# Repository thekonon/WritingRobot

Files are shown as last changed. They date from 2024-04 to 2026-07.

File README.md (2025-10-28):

# WritingRobot
Draw anything using robot!

## Overview

Robot is made of:
- Control part that runs on __Raspberry PI4__
- CAN communication using __MPC2515__ modules
- <del>__Arduino__ Nano clone</del>
- STM32 Bluepill (STM32F103C6T6
- Two __stepper motors drivers__

# Schemes

## Electrical wiring

Arduino:

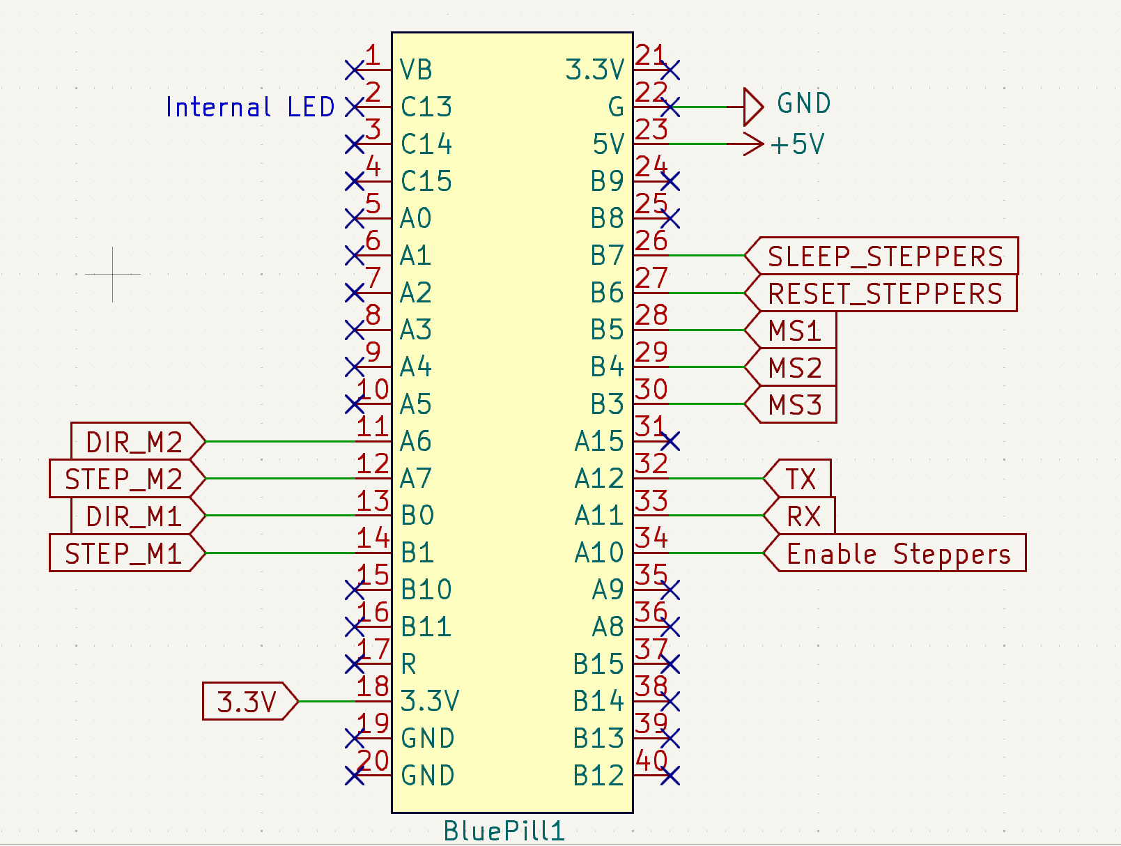
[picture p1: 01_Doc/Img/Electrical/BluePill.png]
Arduino


Stepper motors

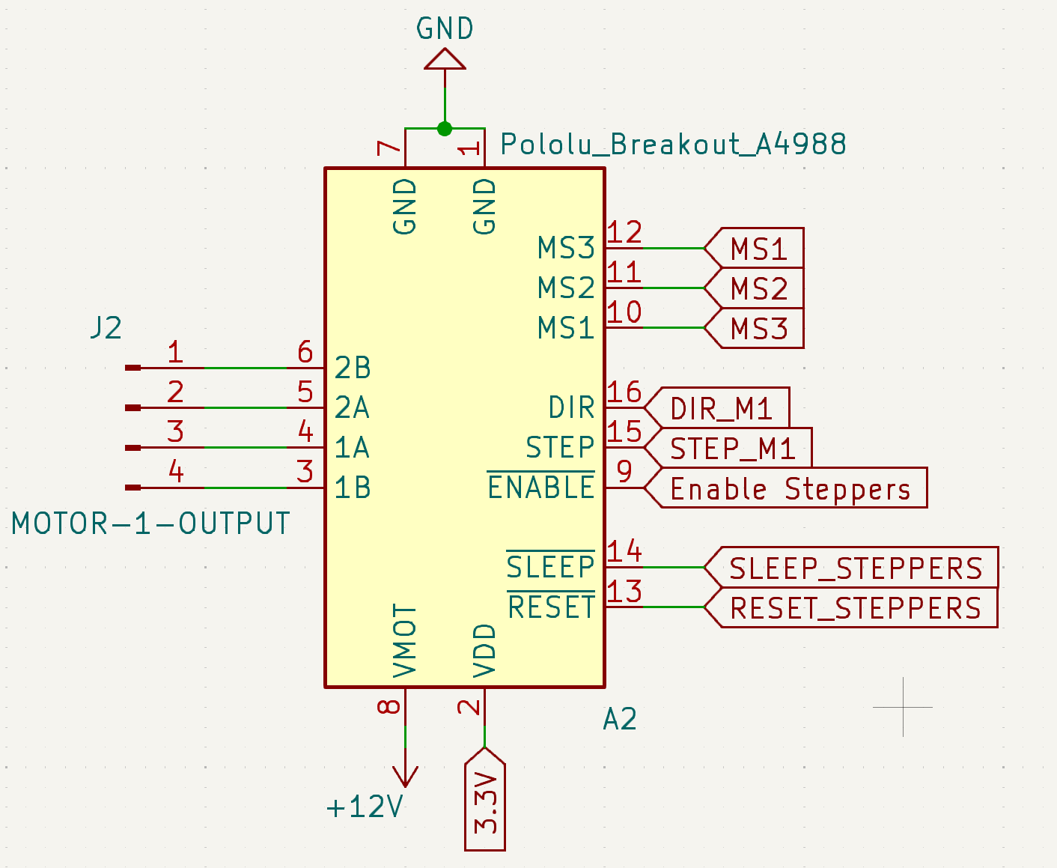
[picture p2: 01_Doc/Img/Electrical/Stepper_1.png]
Stepper1

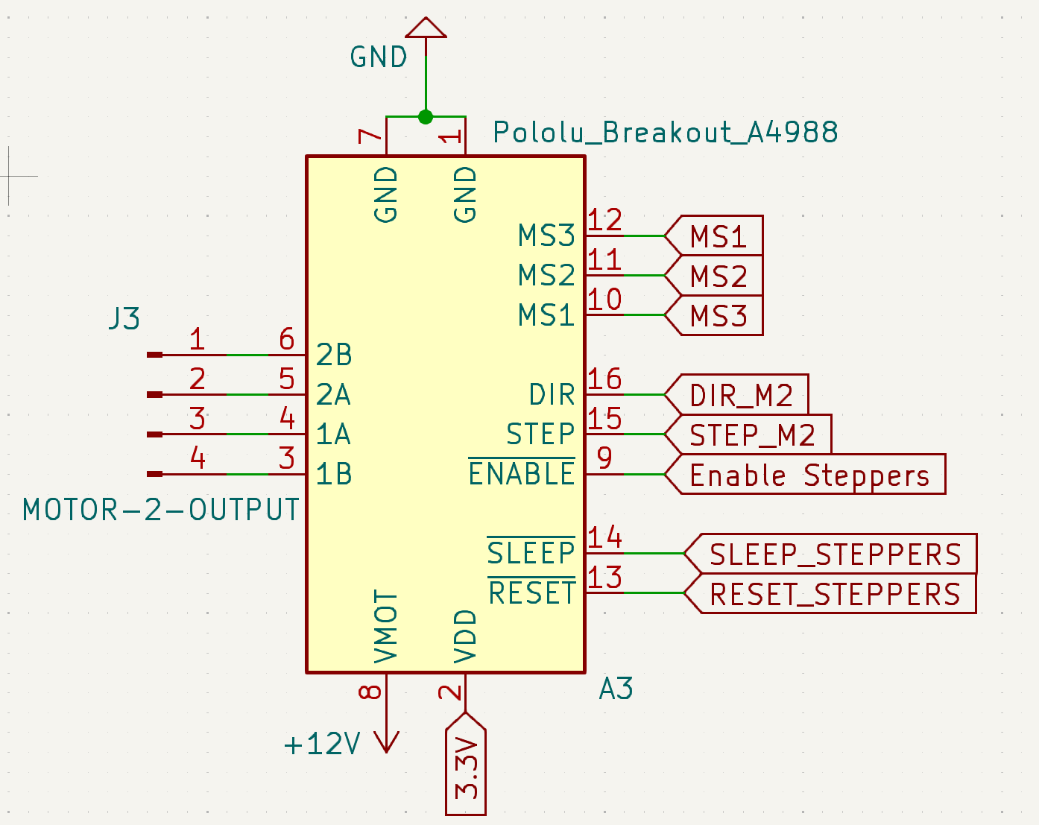
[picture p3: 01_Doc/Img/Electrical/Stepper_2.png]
Stepper2


Powerline

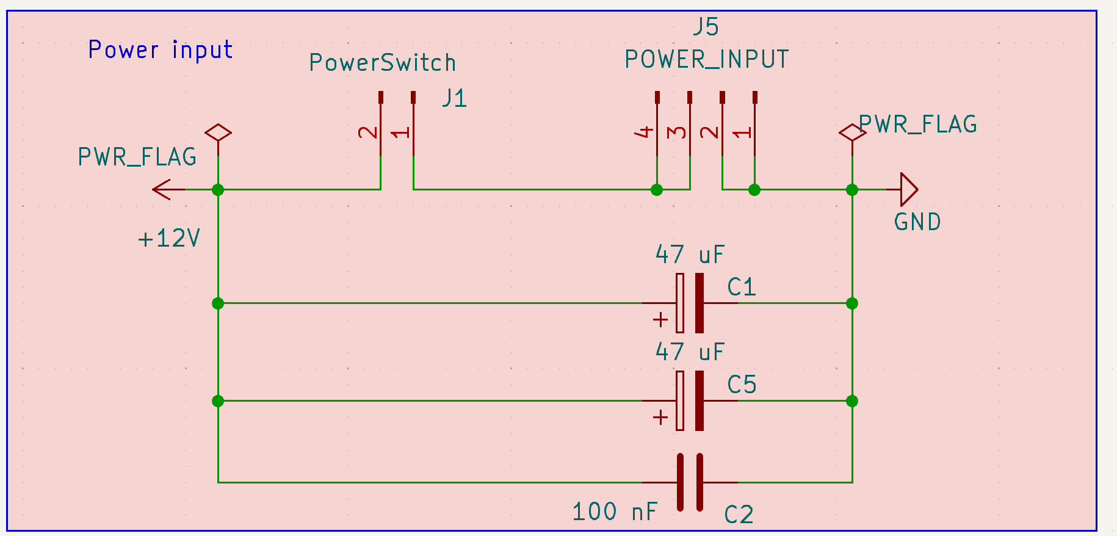
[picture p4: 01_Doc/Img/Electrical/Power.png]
POWERLINE


MCP2551 CANH/L -> Rx/Tx data module

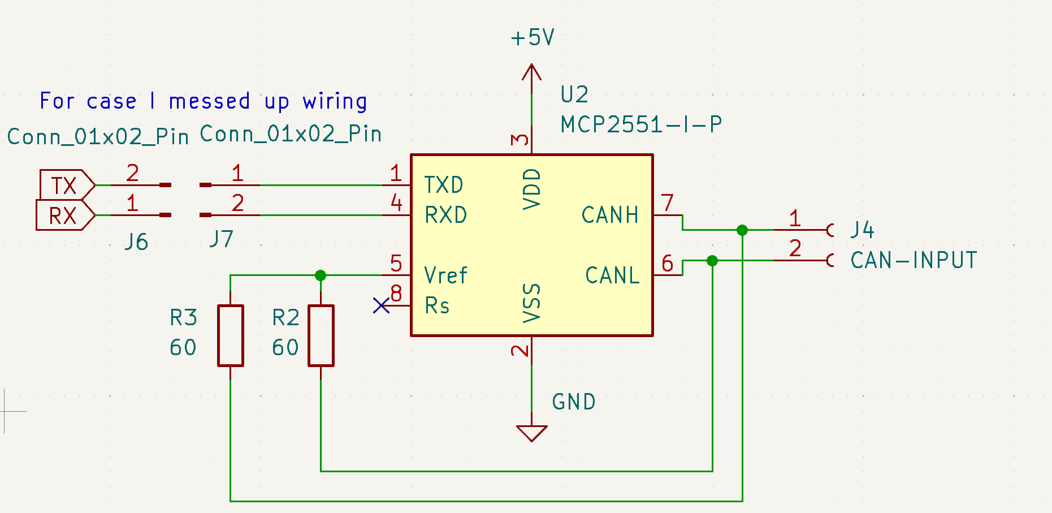
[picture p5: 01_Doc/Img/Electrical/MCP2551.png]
MCP2551


L7805 -> 12V -> 5V/1A 

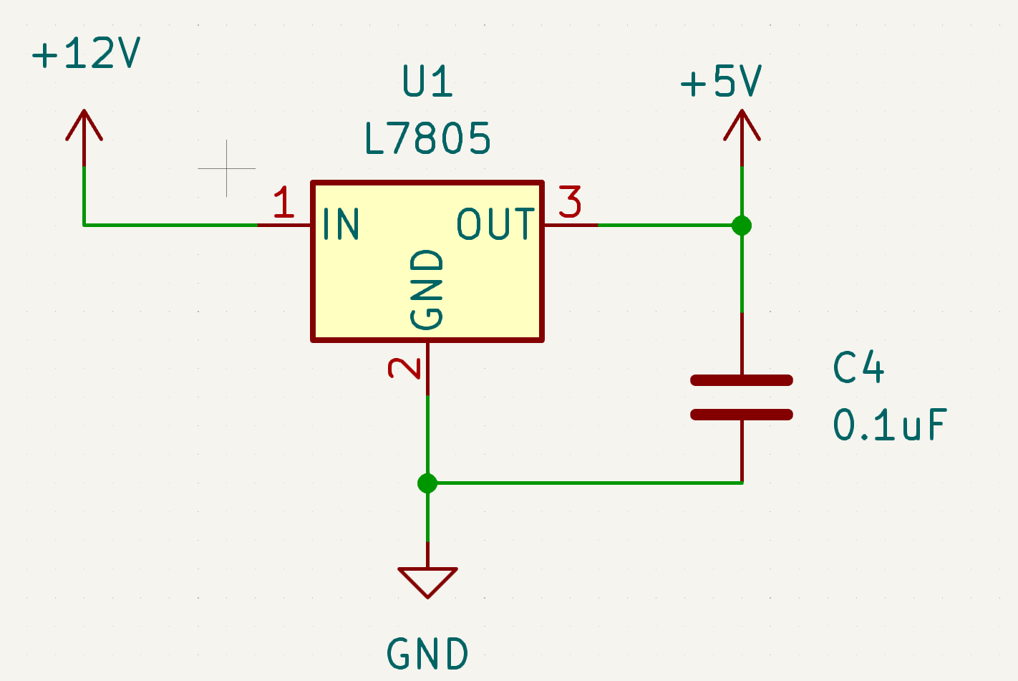
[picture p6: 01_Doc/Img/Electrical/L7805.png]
L7805


## Board design

Wiring scheme of actual PCB

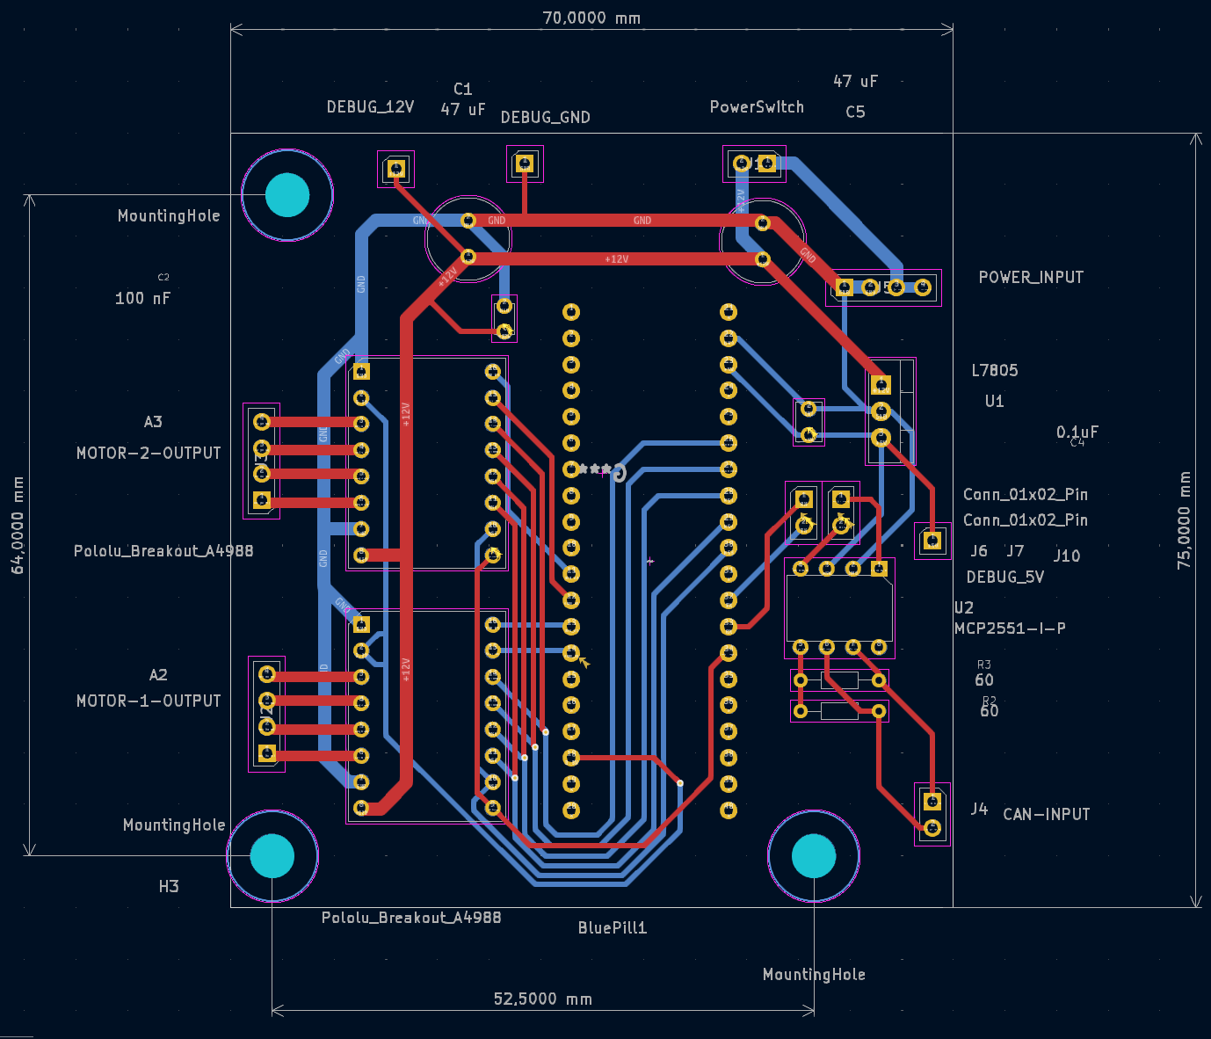
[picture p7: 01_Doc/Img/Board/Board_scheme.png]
BoardScheme


3D view to the board without and with modules

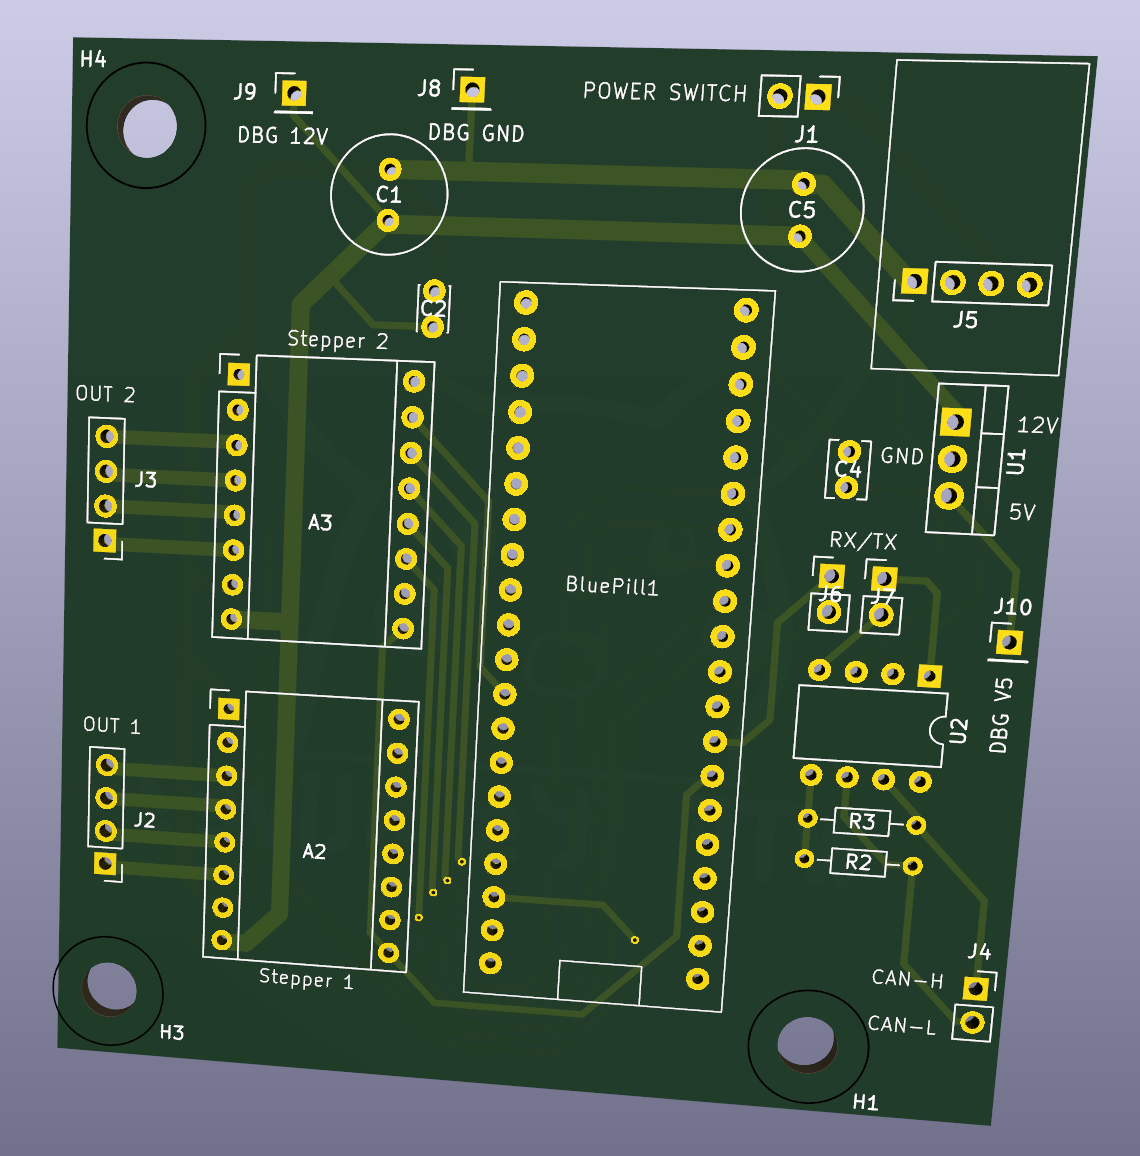
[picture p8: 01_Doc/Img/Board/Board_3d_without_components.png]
BoardWithoutComponents

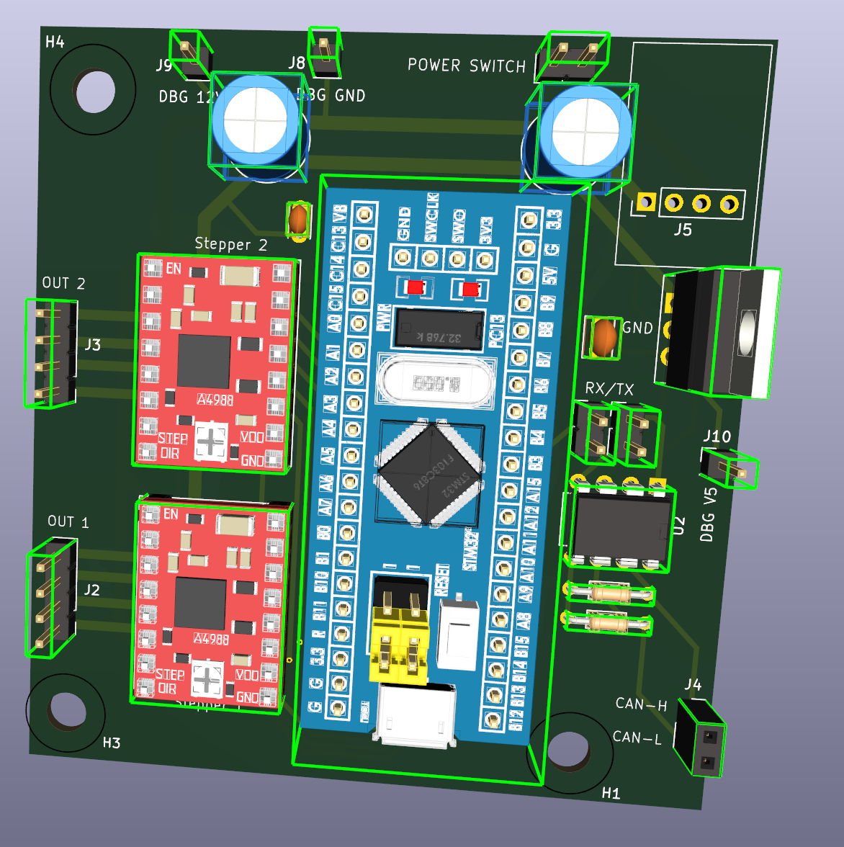
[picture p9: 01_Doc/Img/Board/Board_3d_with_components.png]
BoardWithComponents


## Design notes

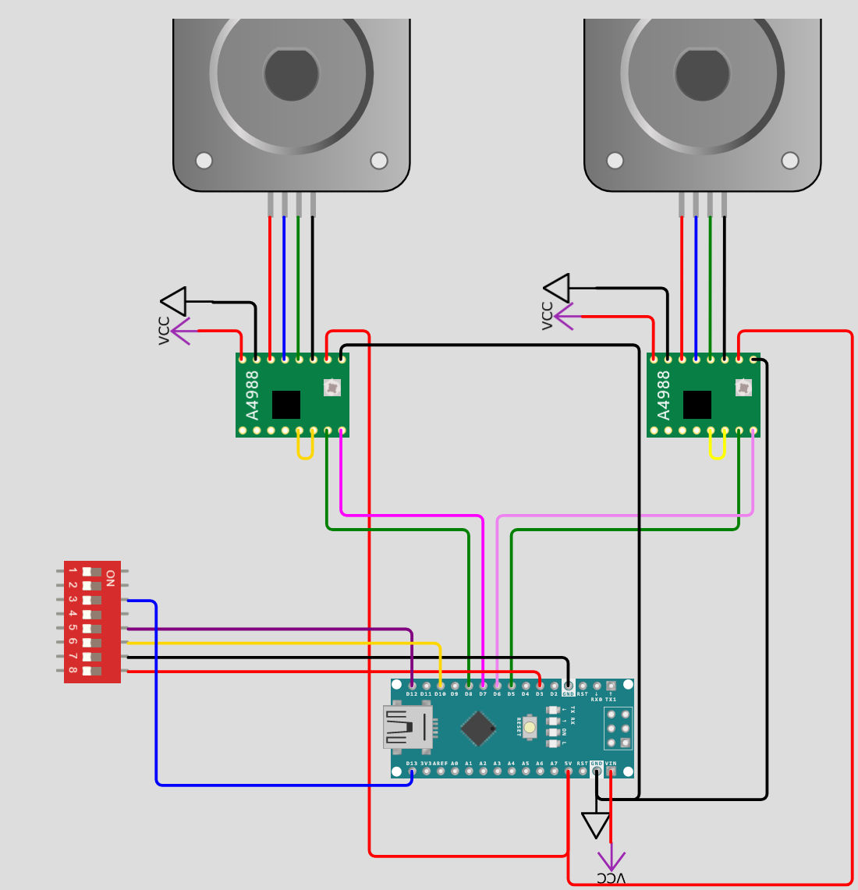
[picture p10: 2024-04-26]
Arduino.png

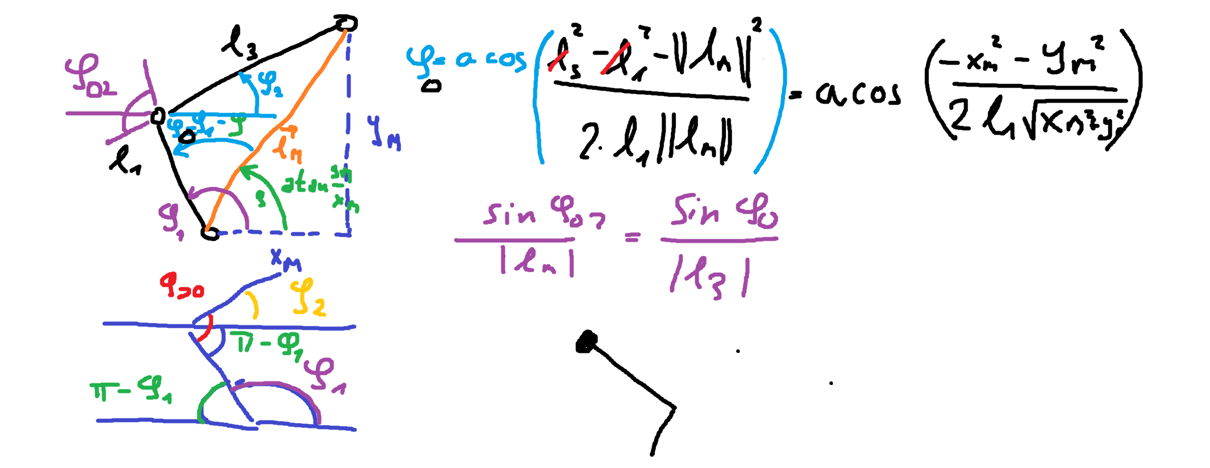
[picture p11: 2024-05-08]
01_Doc/Img/Computation/computation.png

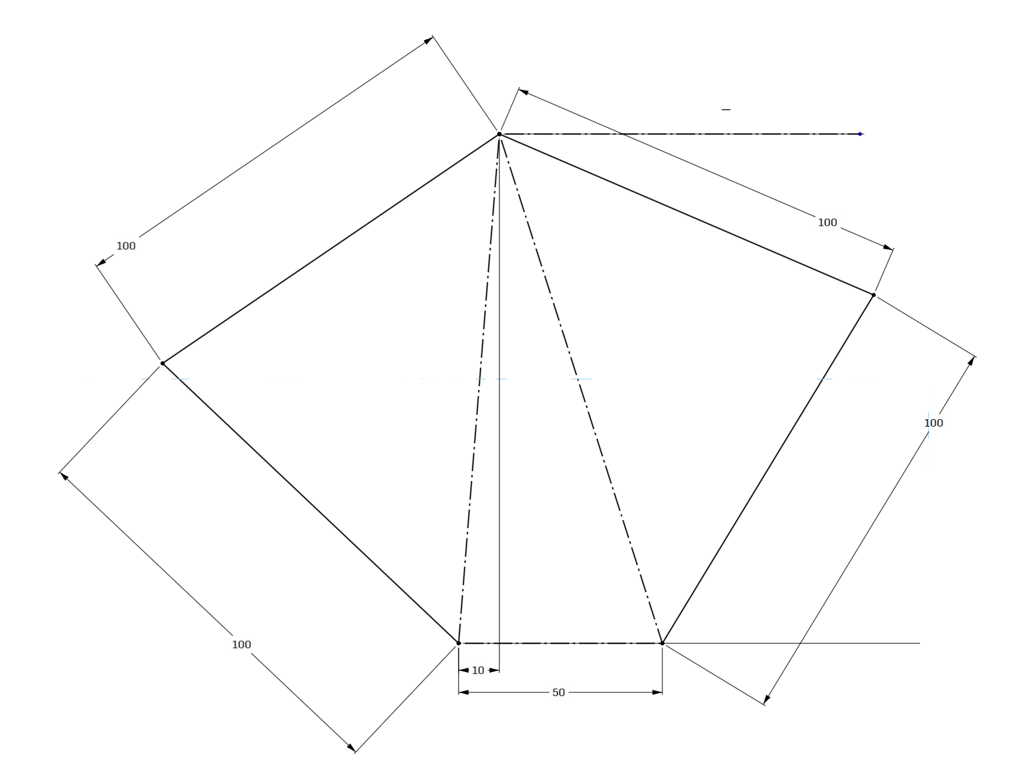
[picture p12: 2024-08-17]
01_Doc/Img/Computation/Comp_new.png

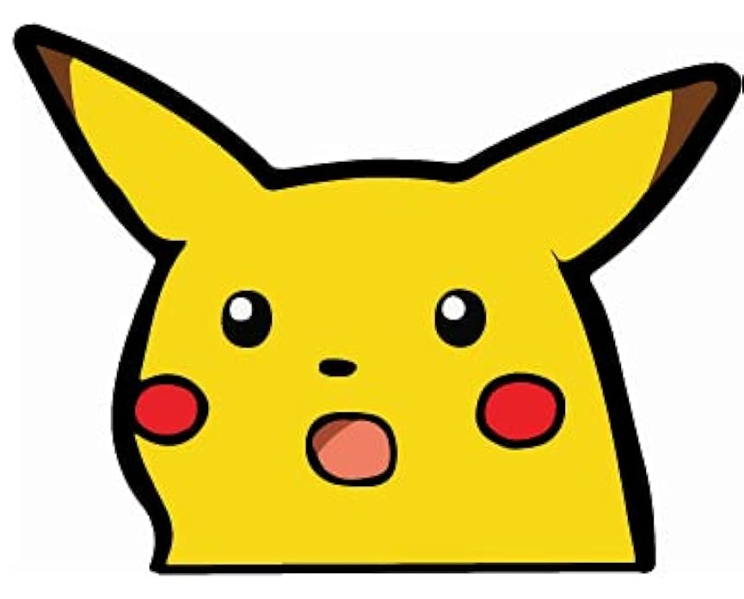
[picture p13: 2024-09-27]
02_HW/board/imgs/pikachu.png

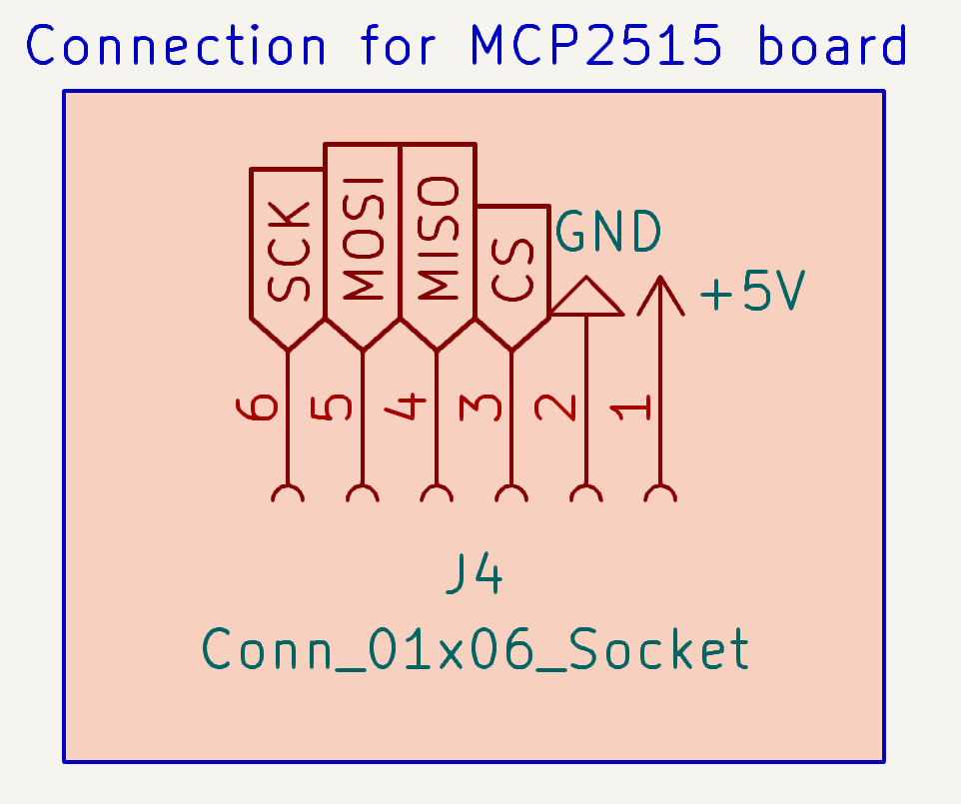
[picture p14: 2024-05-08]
01_Doc/Img/Electrical/MCP2515.png

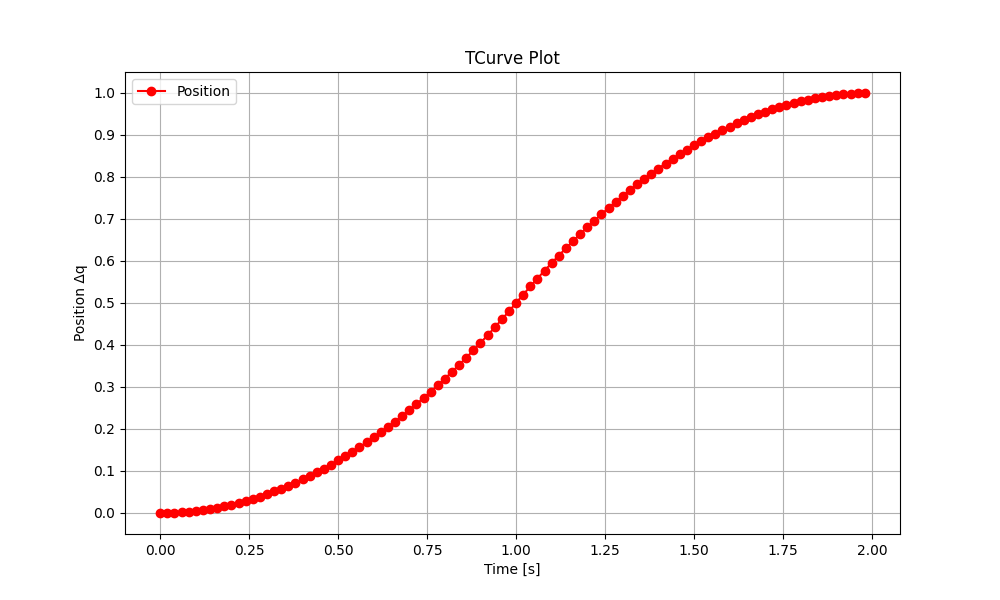
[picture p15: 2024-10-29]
01_Doc/Img/Computation/TCurve/Symetry.png

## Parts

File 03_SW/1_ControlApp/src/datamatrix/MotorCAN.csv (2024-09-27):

Message name | Signal Name | ID | Unit | Length [bits] | Start Bit | Value Range | Initial Value | From | Description
Config_steps | Microstepping_M1 | 100 | / | 3 | 0 | 8 | 8 | MCU | Value of microstepping set up on A4988 for Motor 1
Config_steps | Microstepping_M2 | 100 | / | 3 | 3 | 8 | 8 | MCU | Value of microstepping set up on A4988 for Motor 2
Config_cur_step | Motor_1_cur_step | 101 | / | 14 | 0 | 16384 | 0 | MCU | Current step for Motor 1
Config_cur_step | Motor_2_cur_step | 101 | / | 14 | 14 | 16384 | 0 | MCU | Current step for Motor 2
Config_lengths | Length_1 | 102 | mm | 12 | 0 | 4096 | 100 | MCU | Lenght 1 in mm
Config_lengths | Length_2 | 102 | mm | 12 | 12 | 4096 | 100 | MCU | Lenght 2 in mm
Config_lengths | Length_3 | 102 | mm | 12 | 24 | 4096 | 100 | MCU | Lenght 3 in mm
Config_lengths | Length_4 | 102 | mm | 12 | 36 | 4096 | 100 | MCU | Lenght 4 in mm
Config_lengths | Length_5 | 102 | mm | 12 | 48 | 4096 | 50 | MCU | Lenght 5 in mm
Config_firmware | Major | 103 | / | 8 | 0 | 255 | 0 | MCU | Major version of flashed firmware
Config_firmware | Minor | 103 | / | 8 | 8 | 255 | 0 | MCU | Minor version of flashed firmware
Req_mcu | Microsteps | 50 | / | 1 | 0 | 2 | 0 | * | Request MCU to broadcast Config_steps msg
Req_mcu | Cur_steps | 50 | / | 1 | 1 | 2 | 0 | * | Request MCU to broadcast Config_cur_step msg
Req_mcu | Lengths | 50 | / | 1 | 2 | 2 | 0 | * | Request MCU to broadcast Config_Lengths msg
Req_mcu | Firmware | 50 | / | 1 | 3 | 2 | 0 | * | Request MCU to broadcast Config_firmware msg
Set_motors | Motor_1 | 10 | / | 32 | 0 | 4294967296 | 0 | Controller | Set step for motor 1
Set_motors | Motor_2 | 10 | / | 32 | 32 | 4294967296 | 0 | Controller | Set step for motor 2
Set_stepps | Motor_1 | 15 | / | 65 | 0 | 16384 | 0 | Controller | Set step for motor 1 without moving motors

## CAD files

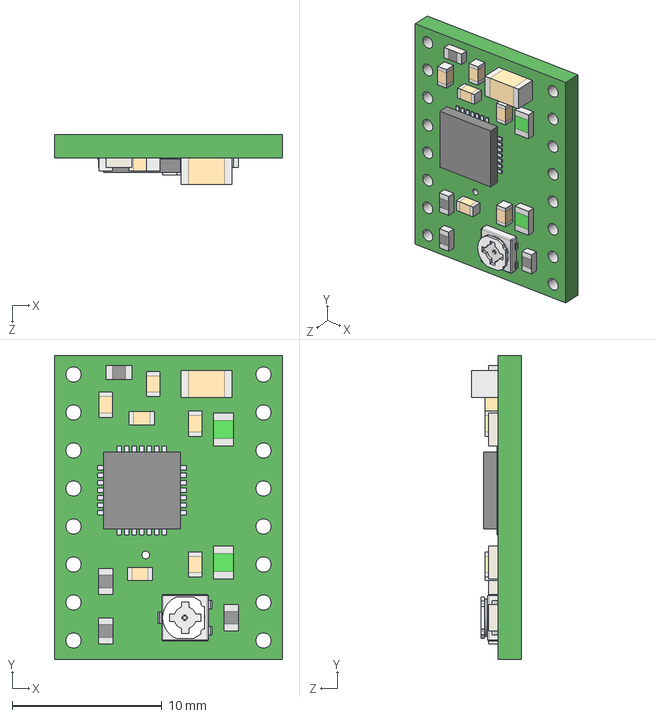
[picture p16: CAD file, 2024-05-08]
02_HW/board/extra_models/a4988-stepper-motor-driver-carrier.step
15.2 x 20.3 x 3.37 mm

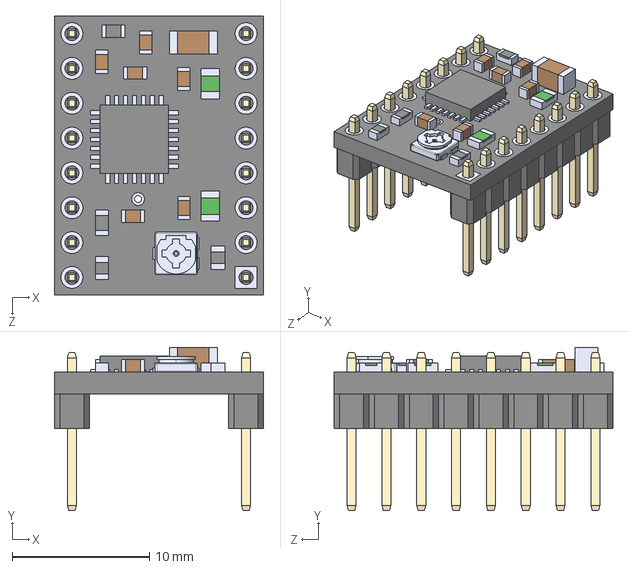
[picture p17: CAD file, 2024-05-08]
02_HW/board/extra_models/A4988 STEPPER MOTOR DRIVER CARRIER--3DModel-STEP-56544.STEP
15.2 x 11.9 x 20.3 mm

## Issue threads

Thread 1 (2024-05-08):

Add electric schamatics to README

thekonon, 2024-05-08:
Get screen shots from KiCAD and put it to main README or create a Wiki page for that reason.

thekonon, 2024-05-08:
Solved
Schematics added

Closed 2024-05-08.

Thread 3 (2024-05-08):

Board design improvement

thekonon, 2024-05-08:
Current board design has many flaws.
- It lacks of all capacitors
- Wire thickness is the same for power and signal lines

Improving electric schematics and board design is necessary

thekonon, 2024-06-14:
Board was updated to more robust version in DEV 0fea8d8758f1854dfbefbe87e100ff577dfcd0db

thekonon, 2024-06-14:
It would be good to add the probe points - for osciloscope

thekonon, 2024-07-13:
New screenshots from new board are needed in readme.

thekonon, 2024-08-17:
Current board implementation -> the one utilized STM bluepill contains filtering capacitor in the input side, as well as 5V regulator

thekonon, 2024-09-25:
New board added, but I missed probe points, needs to be added before sending to manifacture

Closed 2024-10-23.

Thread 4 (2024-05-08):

Add tests for python modules

thekonon, 2024-05-08:
More python tests needs to be added so the code for robot control will be robust.

thekonon, 2024-06-14:
Check if exists eventually add them:

- Test of new CAN frame
- Add the test for arduino

thekonon, 2024-08-17:
Tests for arduino are not needed anymore, creation of communication libraries for STM is now topic

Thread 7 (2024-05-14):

Redesign CAN Message frame

thekonon, 2024-05-14:
Currently the idea is to split 8 bytes long CAN message to 4 + 4 bytes for each motor. The 4 bytes has following meaning:

- First byte is sign byte 0 = +, 1 = -
- Second and third bytes are the whole number angles in range 0-360 basicly
- last byte stands for decimal number

This is described inside value_to_hex function inside _helpers.py in control folder
```
        # 1st byte      - sign 0 - +
        # 2nd/3rd byte  - value before decimal
        # 4th byte      - after decimal value
        # e.g. 347.36 -> [0, 1, 91, 36]
```
The idea is that the sign is not needed at all and for bytes could be used as:
2 bytes for whole numbers
2 bytes for 3 decimal

e.g. 276.654° would be ->
01 14 (.) 02 8E

If this will be implemented, tests will need modifications, but most importantly the arduino code for reading CAN msgs will need to modify acordingly

thekonon, 2024-08-17:
This has been discussed, still shity design not utilizing full potencial of CAN msg. New plan is:

1. Have one msgs id to send 2 * 32 bit numbers representing a wanted state of motor
- that means if I have 19200 steps per revolution and current state is 0, sending 1678 means i want to move motor to 1678 state
- also msgs that sets or asks for current configuration is cool feature

So now python communication module should not send angle values but rather steps state of each motor. This has to be implemented.

thekonon, 2024-09-25:
New format is defined in MotorCAN communication definition in src/datamatrix

Message name,Signal Name,ID,Unit,Length [bits],Start Bit,Value Range,Initial Value,From,Description
Set_motors,Motor_1,10,/,32,0,4294967296,0,Controller,Set step for motor 1
Set_motors,Motor_2,10,/,32,32,4294967296,0,Controller,Set step for motor 2

Closed 2024-09-25.

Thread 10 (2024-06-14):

Create a script that does  the linear movement of motors

thekonon, 2024-06-14:
E.g. arduino gets info that it should move 30 steps with motor A and 45 with motor B, create a function that will send the steps to motors the way it is aproximately a strait line.

Advanced - add the circles / arcs

thekonon, 2024-10-23:
STM chip should get info about x and y position and interpolate linear movement there, this issue is pointless now

Closed 2024-10-23.

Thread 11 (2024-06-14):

Add a arduino script to project

thekonon, 2024-06-14:
Currently the arduino code is only in my PC, It is necessary to add it to the Git

thekonon, 2024-08-17:
Great to have it but, I'll move to STM32 (blupill probably) so this code is no longer needed. On the other hand new ticket for including STMCube code will be necessary

Closed 2024-08-17.

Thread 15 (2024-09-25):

Find out a best control strategy for controlling speed of the motors

thekonon, 2024-09-25:
MSGs over the CAN will send needed step position of the motors, STM should handle smooth acceleration and decceleration for smother movement of whole robot. Question is how to do that.

Ideas:
- add a msgs indicating to slow down

thekonon, 2024-10-23:
Currently it seems I will split my traectory to linear parts and each linear part will be controlled via timer interruption - i have to write about it to wiki

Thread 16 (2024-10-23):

Lessons learned - board design

thekonon, 2024-10-23:
Mistakes:

- The DC connection is not fitting -> it should have been closer to edge or use directly DC jack mount
- Make edges rounded
- Add holes dimesions to PCB silk layer on back

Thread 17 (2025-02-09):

Remove MS3 from BP3 and use it as a SWO pin.

thekonon, 2025-02-09:
Recently I found out for SWV you have to have SWO pin connected to STM LINK, unfortunately I have connected MS3 signal to that pin. Redesigning a board with this feature is a must.

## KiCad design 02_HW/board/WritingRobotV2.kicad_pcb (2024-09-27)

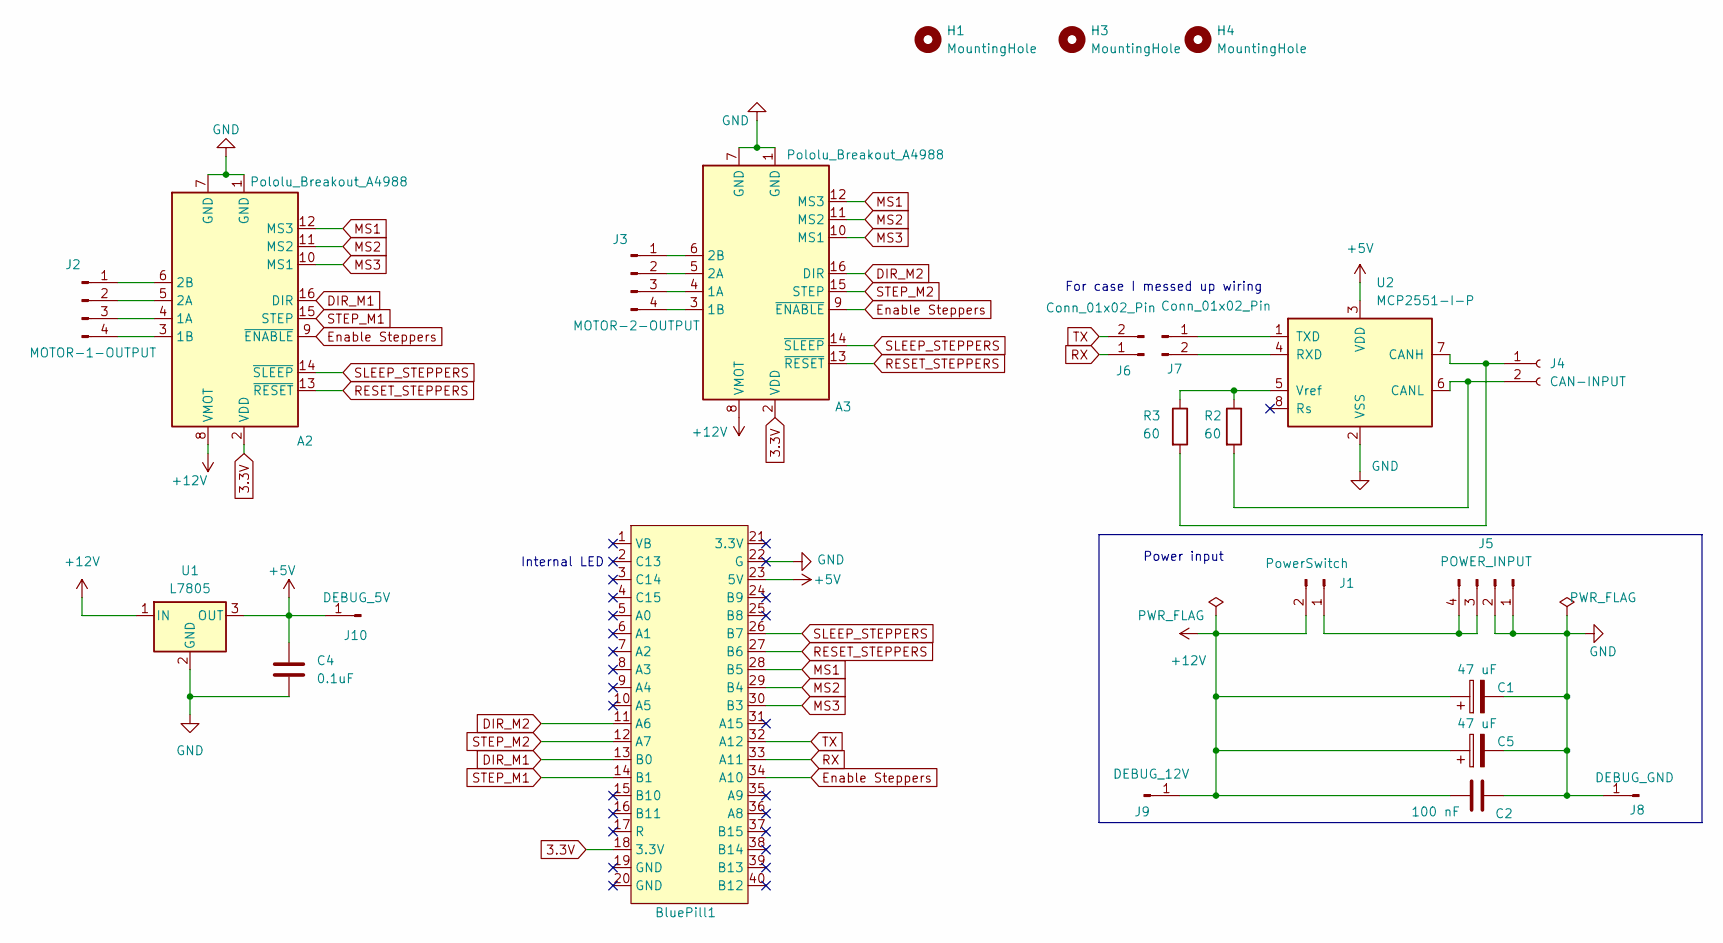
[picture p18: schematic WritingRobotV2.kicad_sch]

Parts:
A2, A3: Pololu_Breakout_A4988; Pololu_Breakout-16_15.2x20.3mm
BluePill1: BluePill
C1, C5: 47 uF; C_Radial_D8.0mm_H11.5mm_P3.50mm
C2: 100 nF; C_Disc_D3.0mm_W2.0mm_P2.50mm
C4: 0.1uF; C_Disc_D3.8mm_W2.6mm_P2.50mm
H1, H3, H4: MountingHole; MountingHole_4.3mm_M4
J1: PowerSwitch; PinHeader_1x02_P2.54mm_Vertical
J2: MOTOR-1-OUTPUT; PinHeader_1x04_P2.54mm_Vertical
J3: MOTOR-2-OUTPUT; PinHeader_1x04_P2.54mm_Vertical
J4: CAN-INPUT; PinSocket_1x02_P2.54mm_Vertical
J5: POWER_INPUT; PinHeader_1x04_P2.54mm_Vertical
J6, J7: Conn_01x02_Pin; PinHeader_1x02_P2.54mm_Vertical
J8: DEBUG_GND; PinHeader_1x01_P2.54mm_Vertical
J9: DEBUG_12V; PinHeader_1x01_P2.54mm_Vertical
J10: DEBUG_5V; PinHeader_1x01_P2.54mm_Vertical
R2, R3: 60; R_Axial_DIN0204_L3.6mm_D1.6mm_P7.62mm_Horizontal
U1: L7805; TO-220-3_Vertical
U2: MCP2551-I-P; DIP-8_W7.62mm

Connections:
3.3V: A2.2 (VDD), A3.2 (VDD), BluePill1.18 (3.3V)
+5V: BluePill1.23 (5V), C4.1, J10.1, U1.3 (OUT), U2.3 (VDD)
+12V: A2.8 (VMOT), A3.8 (VMOT), C1.1, C2.1, C5.1, J1.2, J9.1, U1.1 (IN)
DIR_M1: A2.16 (DIR), BluePill1.13 (B0)
DIR_M2: A3.16 (DIR), BluePill1.11 (A6)
Enable Steppers: A2.9 (~ENABLE), A3.9 (~ENABLE), BluePill1.34 (A10)
GND: A2.1 (GND), A2.7 (GND), A3.1 (GND), A3.7 (GND), BluePill1.22 (G), C1.2, C2.2, C4.2, C5.2, J5.1, J5.2, J8.1, U1.2 (GND), U2.2 (VSS)
MS1: A2.12 (MS3), A3.12 (MS3), BluePill1.28 (B5)
MS2: A2.11 (MS2), A3.11 (MS2), BluePill1.29 (B4)
MS3: A2.10 (MS1), A3.10 (MS1), BluePill1.30 (B3)
unnamed: A2.4 (1A), J2.3
unnamed: A2.3 (1B), J2.4
unnamed: A2.5 (2A), J2.2
unnamed: A2.6 (2B), J2.1
unnamed: A3.4 (1A), J3.3
unnamed: A3.3 (1B), J3.4
unnamed: A3.5 (2A), J3.2
unnamed: A3.6 (2B), J3.1
unnamed: J1.1, J5.3, J5.4
unnamed: J4.1, R3.2, U2.7 (CANH)
unnamed: J4.2, R2.2, U2.6 (CANL)
unnamed: J7.1, U2.1 (TXD)
unnamed: J7.2, U2.4 (RXD)
unnamed: R2.1, R3.1, U2.5 (Vref)
RESET_STEPPERS: A2.13 (~RESET), A3.13 (~RESET), BluePill1.27 (B6)
RX: BluePill1.33 (A11), J6.1
SLEEP_STEPPERS: A2.14 (~SLEEP), A3.14 (~SLEEP), BluePill1.26 (B7)
STEP_M1: A2.15 (STEP), BluePill1.14 (B1)
STEP_M2: A3.15 (STEP), BluePill1.12 (A7)
TX: BluePill1.32 (A12), J6.2

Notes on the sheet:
Internal LED
Power input
For case I messed up wiring

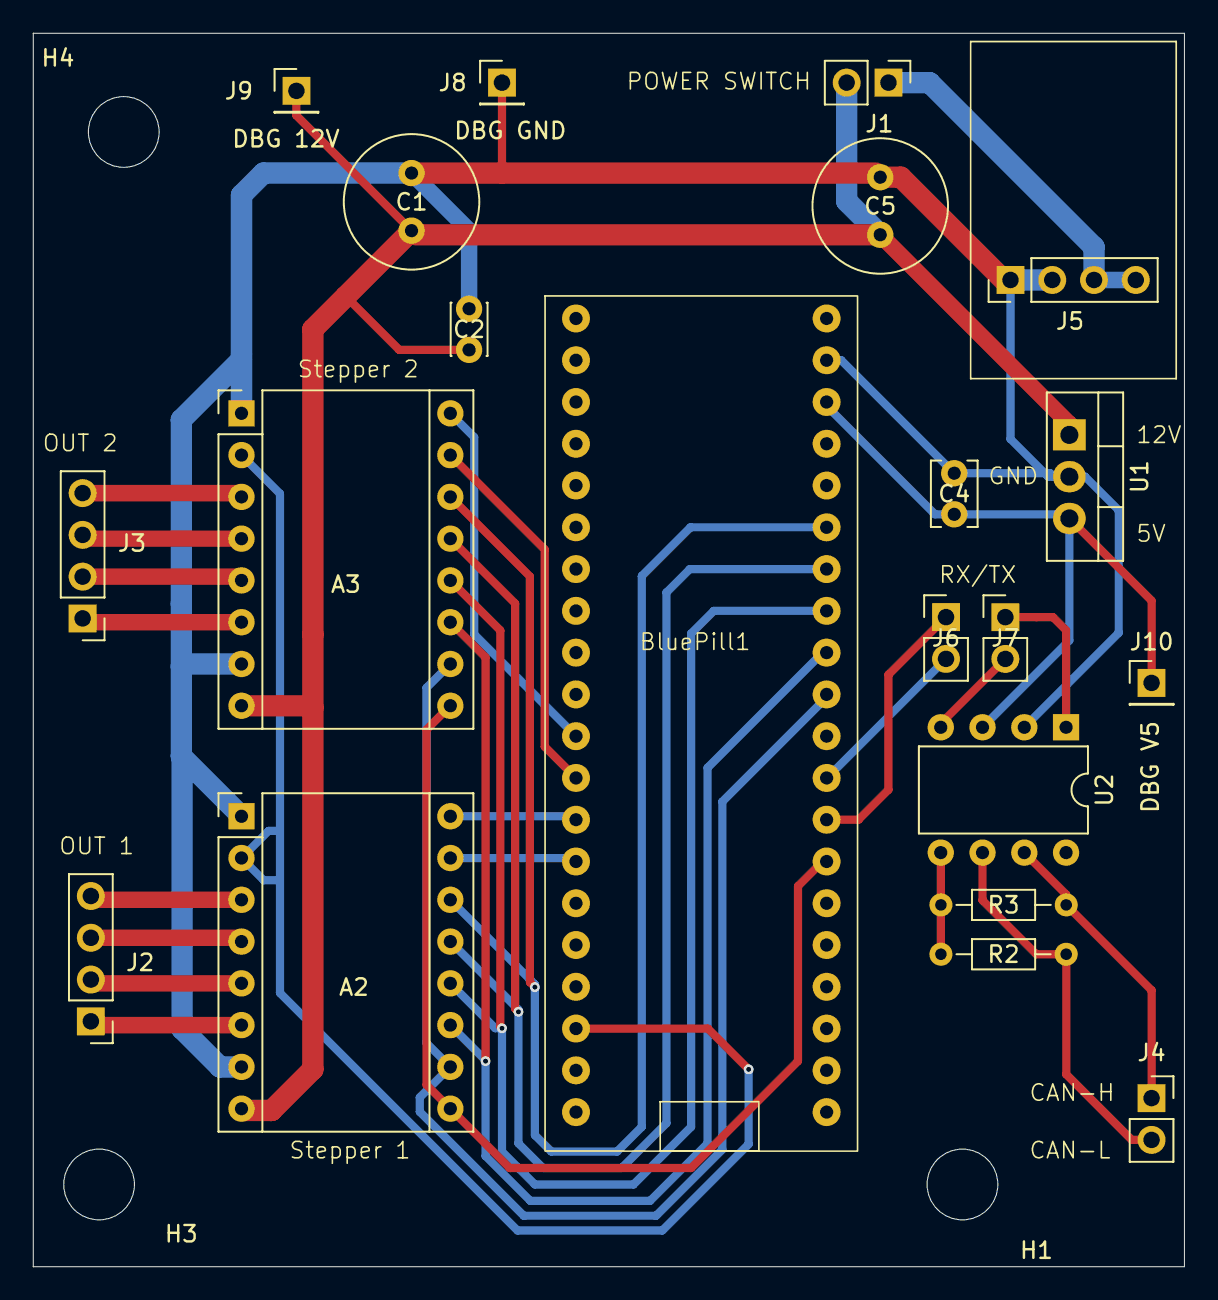
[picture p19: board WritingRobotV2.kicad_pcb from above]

Board: 2 copper layers, 70.0 x 75.0 mm, 24 parts (0 on the bottom side), 30 nets.

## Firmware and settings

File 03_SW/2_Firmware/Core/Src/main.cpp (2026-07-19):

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
/* Includes ------------------------------------------------------------------*/
#include "main.h"

CAN_HandleTypeDef hcan;

TIM_HandleTypeDef htim1;
TIM_HandleTypeDef htim2;
TIM_HandleTypeDef htim3;

void SystemClock_Config(void);
static void MX_GPIO_Init(void);
static void MX_CAN_Init(void);
static void MX_TIM2_Init(void);
static void MX_TIM1_Init(void);
static void MX_TIM3_Init(void);
static void MX_NVIC_Init(void);
/* USER CODE BEGIN 0 */

void HAL_TIM_PeriodElapsedCallback(TIM_HandleTypeDef *htim)
{
	if (htim->Instance == TIM2)
	{
		// Your interrupt code here (runs every 100 µs)
		HAL_GPIO_TogglePin(STEP_1_GPIO_Port, STEP_1_Pin);
		HAL_GPIO_TogglePin(STEP_2_GPIO_Port, STEP_2_Pin);
	}
}

void update_timer_period_us(uint32_t microseconds)
{
	uint32_t ticks = microseconds - 1; // at 1 MHz base
	__HAL_TIM_DISABLE(&htim2);         // optional: stop timer briefly
	__HAL_TIM_SET_AUTORELOAD(&htim2, ticks);
	__HAL_TIM_SET_COUNTER(&htim2, 0);  // reset counter if you want a clean start
	__HAL_TIM_ENABLE(&htim2);          // restart
}

/* USER CODE END 0 */

/**
 * @brief  The application entry point.
 * @retval int
 */
int main(void)
{

	/* MCU Configuration--------------------------------------------------------*/

	/* Reset of all peripherals, Initializes the Flash interface and the Systick. */
	HAL_Init();

	/* Configure the system clock */
	SystemClock_Config();

	/* Initialize all configured peripherals */
	MX_GPIO_Init();
	MX_CAN_Init();
	MX_TIM2_Init();
	MX_TIM1_Init();
	MX_TIM3_Init();

	/* Initialize interrupts */
	MX_NVIC_Init();
	/* USER CODE BEGIN 2 */
	// Enable interrupts
	HAL_TIM_Base_Start_IT(&htim2);

	// Enable stepper motors
	HAL_GPIO_WritePin(ENABLE_STEPPERS_GPIO_Port, ENABLE_STEPPERS_Pin, GPIO_PIN_RESET);
	HAL_GPIO_WritePin(SLEEP_STEPPERS_GPIO_Port, SLEEP_STEPPERS_Pin, GPIO_PIN_SET);
	HAL_GPIO_WritePin(RESET_STEPPERS_GPIO_Port, RESET_STEPPERS_Pin, GPIO_PIN_SET);

	HAL_GPIO_WritePin(DIR_1_GPIO_Port, DIR_1_Pin, GPIO_PIN_RESET);
	HAL_GPIO_WritePin(DIR_2_GPIO_Port, DIR_2_Pin, GPIO_PIN_RESET);
	HAL_GPIO_WritePin(STEP_1_GPIO_Port, STEP_1_Pin, GPIO_PIN_RESET);
	HAL_GPIO_WritePin(STEP_2_GPIO_Port, STEP_2_Pin, GPIO_PIN_RESET);

	TCurve curve;

	curve.setAcceleration(50.0f);
	curve.setDeltaPhi(10.0f);
	curve.setMaxVelocity(25.0f);

	if(curve.recalculateInternalVariables() != TCurveError::OK) Error_Handler();

	float t_max = curve.getTMax();

	/* USER CODE END 2 */

	/* Infinite loop */
	/* USER CODE BEGIN WHILE */
	uint32_t new_period = 200 - 1;   // 200 µs
	while (1)
	{
		/* USER CODE END WHILE */

		/* USER CODE BEGIN 3 */
		HAL_GPIO_TogglePin(LED_GPIO_Port, LED_Pin);
		HAL_Delay(500);
	}
	/* USER CODE END 3 */
}

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


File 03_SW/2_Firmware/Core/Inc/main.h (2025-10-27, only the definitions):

#define LED_Pin GPIO_PIN_13
#define LED_GPIO_Port GPIOC
#define DIR_2_Pin GPIO_PIN_6
#define DIR_2_GPIO_Port GPIOA
#define STEP_2_Pin GPIO_PIN_7
#define STEP_2_GPIO_Port GPIOA
#define DIR_1_Pin GPIO_PIN_0
#define DIR_1_GPIO_Port GPIOB
#define STEP_1_Pin GPIO_PIN_1
#define STEP_1_GPIO_Port GPIOB
#define ENABLE_STEPPERS_Pin GPIO_PIN_10
#define ENABLE_STEPPERS_GPIO_Port GPIOA
#define MS3_Pin GPIO_PIN_3
#define MS3_GPIO_Port GPIOB
#define MS2_Pin GPIO_PIN_4
#define MS2_GPIO_Port GPIOB
#define MS1_Pin GPIO_PIN_5
#define MS1_GPIO_Port GPIOB
#define RESET_STEPPERS_Pin GPIO_PIN_6
#define RESET_STEPPERS_GPIO_Port GPIOB
#define SLEEP_STEPPERS_Pin GPIO_PIN_7
#define SLEEP_STEPPERS_GPIO_Port GPIOB

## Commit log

2024-04-25 Init commit for files of first board iteration
    [WritingRobotV2-B_Cu.gbl, WritingRobotV2-B_Mask.gbs, WritingRobotV2-B_Paste.gbp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]
2024-05-08 Changed electrical layout Added 3d components to PCB Created photos for DOCU Modified Readme file
2024-05-08 Project saved
    [WritingRobotV2.kicad_pcb]
2024-05-15 Added function value_to_hex_2 that imeplements idea from
    https://github.com/thekonon/WritingRobot/issues/7
    [_helpers.py]
2024-05-25 Resolving errors from pylance
    [_tools.py, main_window.py]
2024-05-25 Resolving another Qt problems
    [main_window.py]
2024-06-01 Gui reworked, it looks better, CAN features connected
    [_tools.py, main_window.py]
2024-06-01 tests repaired, pywin32 removed - raspberry installation problems
    [main_window.py]
2024-06-01 Updated CAN frame calculation
2024-06-11 Board updated
    [WritingRobotV2.kicad_pcb, WritingRobotV2.kicad_sch]
2024-06-15 Minor changes in board
2024-06-15 Added folder for arduino function, CMakeLists.txt contains includes for test
2024-06-15 Remove junk in test/test_helpers.py Added electronics_calculations/main.py for calculation of analog filter
2024-06-15 Arduino constants moved to constants Created constants.h file
2024-06-15 functions for arduino control moving to src folder unit tests added
2024-06-15 Adding new module for controlling the motor
2024-06-18 Compilation in arduino IDE is working
2024-06-20 Minor changes in arduino code
2024-06-21 Test for arduino are working in Platformio
2024-06-21 Removed arduino folder
2024-08-11 Board to stm32
    [WritingRobotV2.kicad_pcb, WritingRobotV2.kicad_sch]
2024-08-16 Saving current work
2024-09-25 Docu update after going to STM32 chip
2024-09-25 Board updated to STM32
    Other files in rework
    [MotorCAN.csv, WritingRobotV2.kicad_pcb, WritingRobotV2.kicad_sch]
2024-09-25 Update README.md
    Update front page arduino -> STM32
2024-09-27 This was send to manufactory
    [MotorCAN.csv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]
2025-10-26 Project restructu
    [A4988 STEPPER MOTOR DRIVER CARRIER--3DModel-STEP-56544.STEP, MotorCAN.csv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]
2025-10-27 add stm32 project

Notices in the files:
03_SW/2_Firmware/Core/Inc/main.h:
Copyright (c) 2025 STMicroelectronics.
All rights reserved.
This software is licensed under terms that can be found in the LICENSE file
